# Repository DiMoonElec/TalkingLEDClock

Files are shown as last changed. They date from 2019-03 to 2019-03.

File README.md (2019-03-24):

# TalkingLEDClock
Говорящие LED-часы с будильником и термометром

Ссылки на статьи:
http://dimoon.ru/category/proektyi/talkingledclock

Структура проекта:  <br>
AT45Dump\ - все, что касается сборки дампа с музыкальными семплами <br>
PCB\ - схема + печатная плата <br>
STM32_Prg\tc_stm32.hex - прошивка МК часов <br>
STM32_Source\ - исходники прошивки часов <br>

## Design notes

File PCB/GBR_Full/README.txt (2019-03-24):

top.gbr - медь верх
mask_top.gbr - маска верх
silk_top.gbr - маркировка верх

bott.gbr - медь низ
mask_bott.gbr - маска низ
silk_bott.gbr - маркировка низ

border.gbr - граница платы

Through_circle.drl - сверловка круглые металлизированные отверстия
Through_ellipse.drl - фрезеровка овальные металлизированные отверстия
Through.drl - неметаллизированные крепежные отверстия

PCB.png - внешний вид заготовки с платами

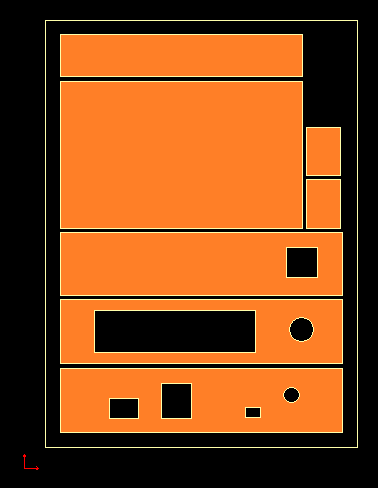
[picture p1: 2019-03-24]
PCB/GBR_Full/PCB.png

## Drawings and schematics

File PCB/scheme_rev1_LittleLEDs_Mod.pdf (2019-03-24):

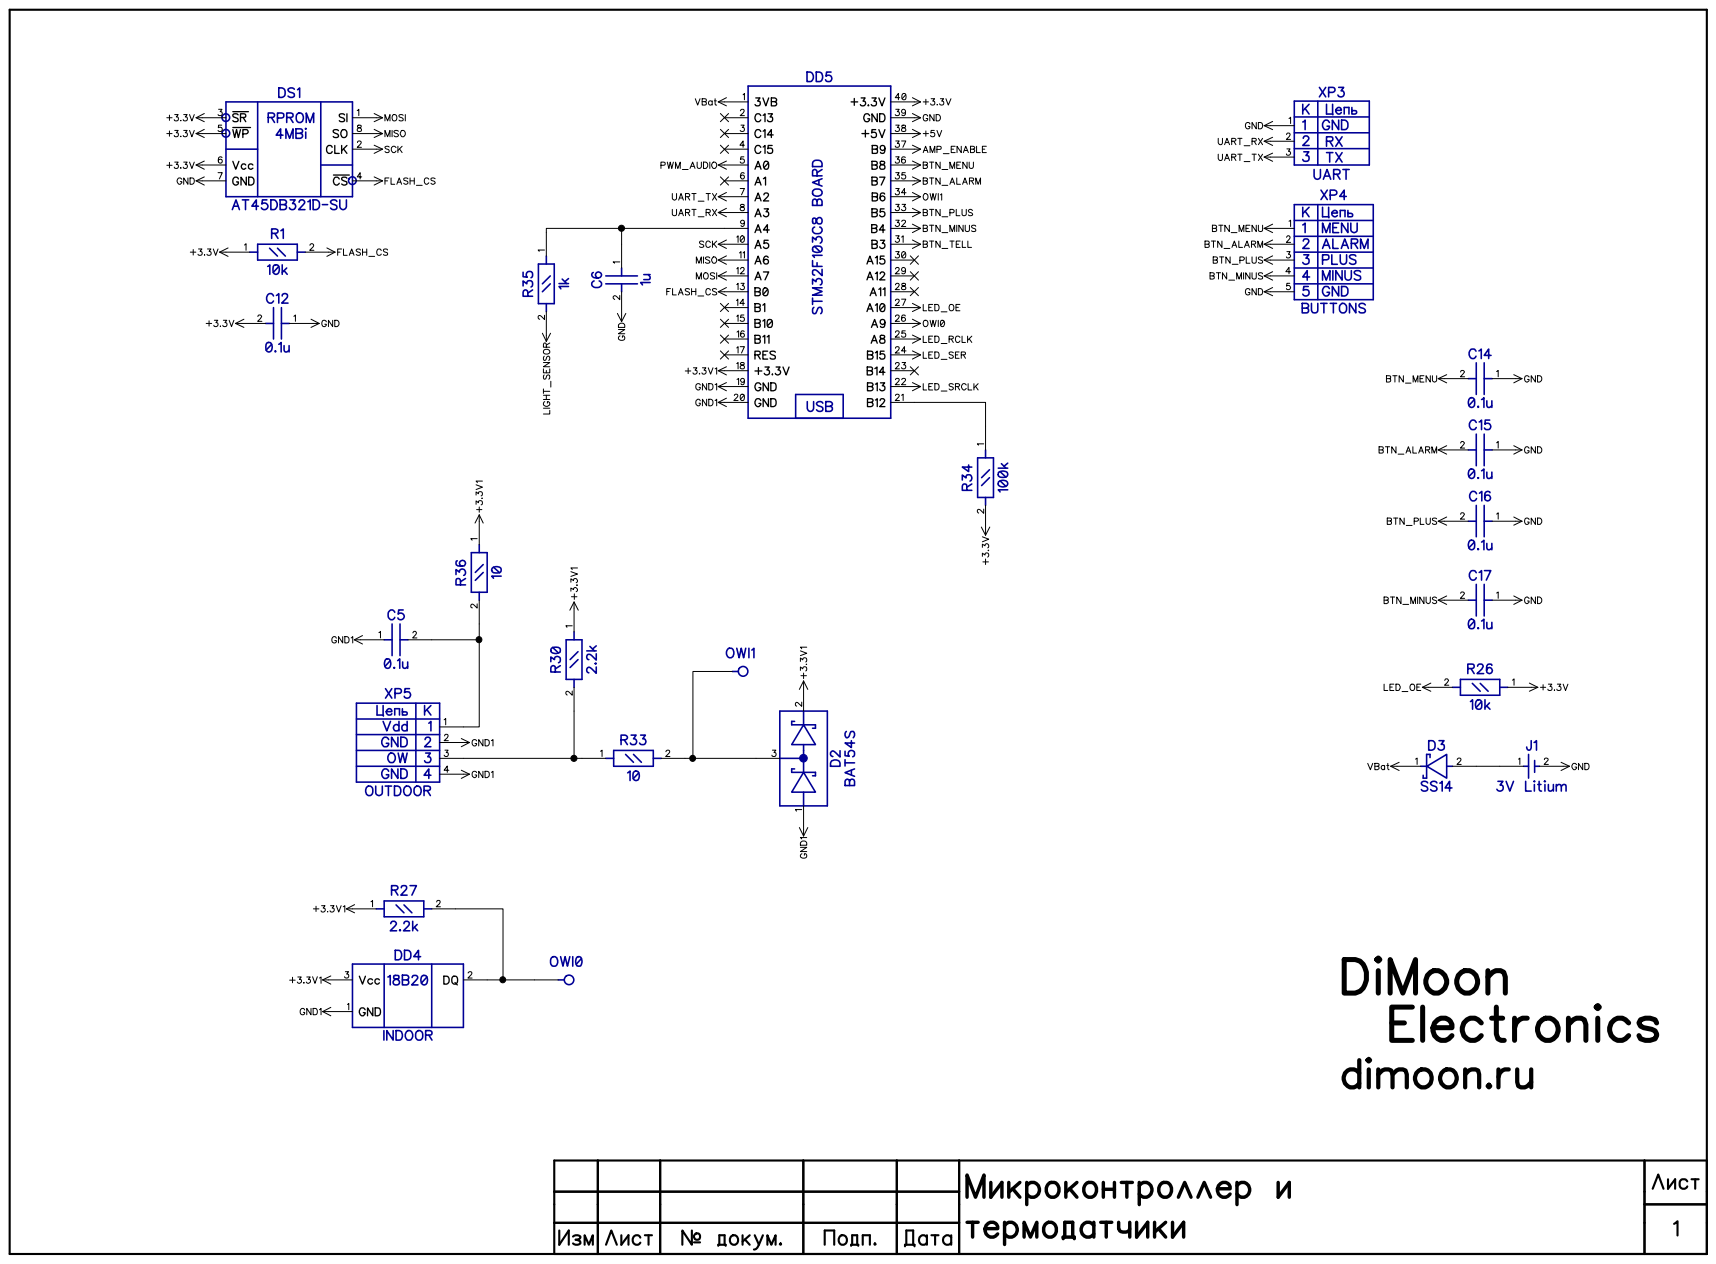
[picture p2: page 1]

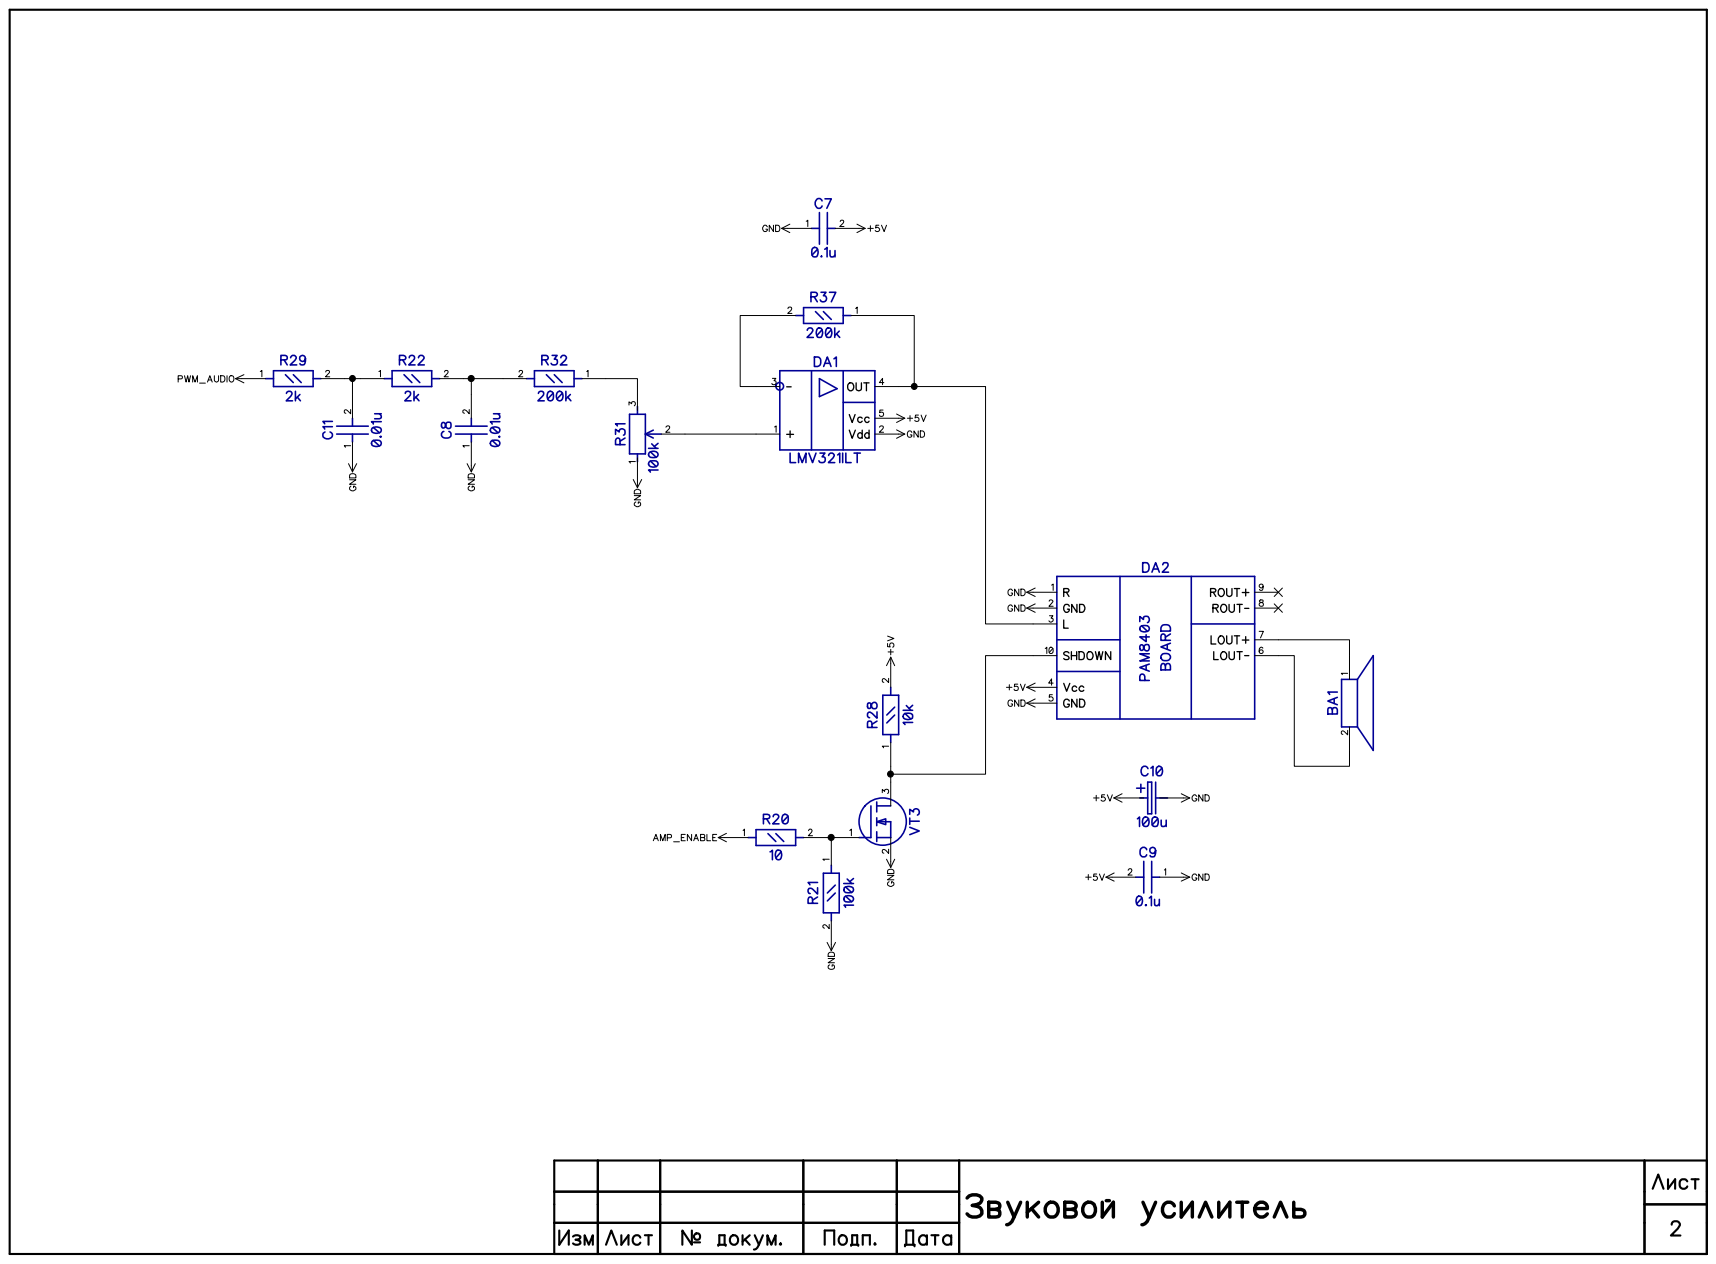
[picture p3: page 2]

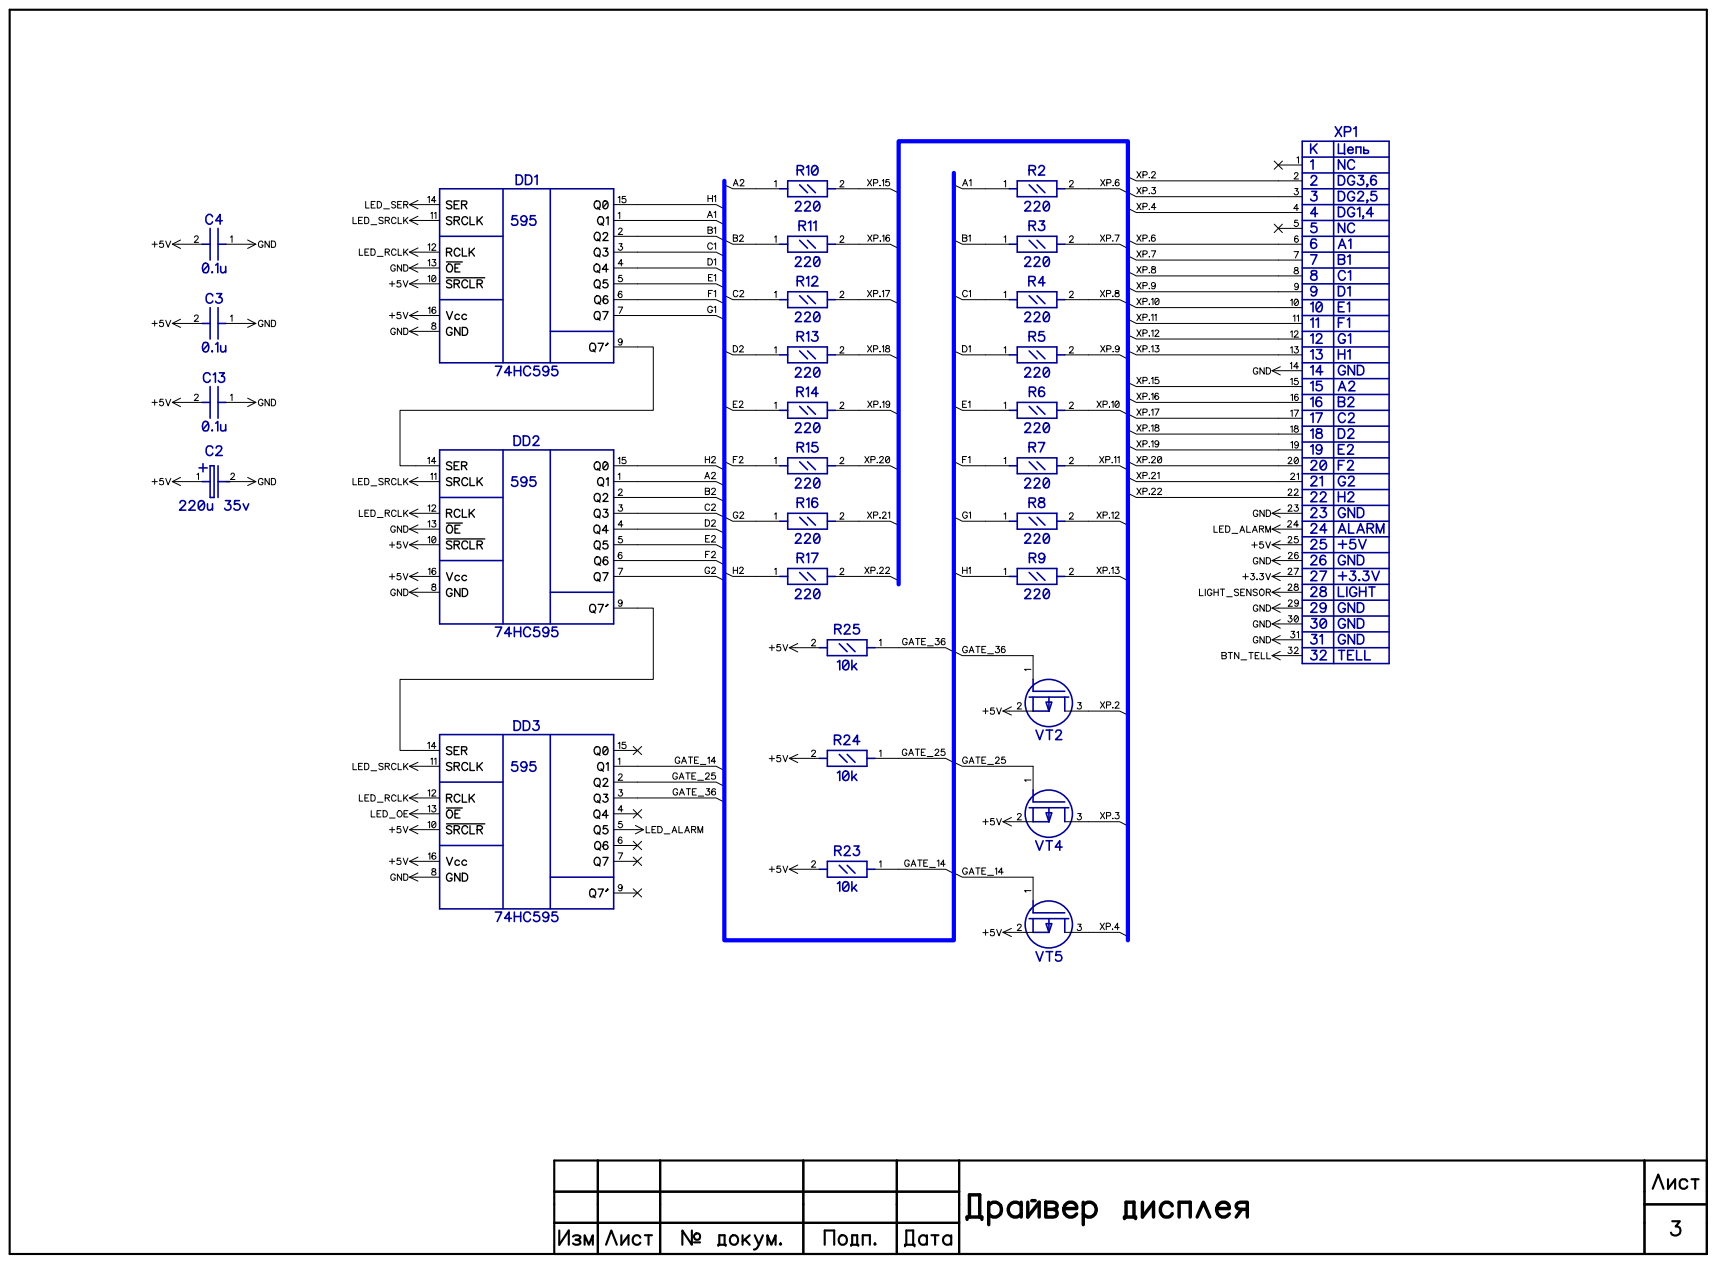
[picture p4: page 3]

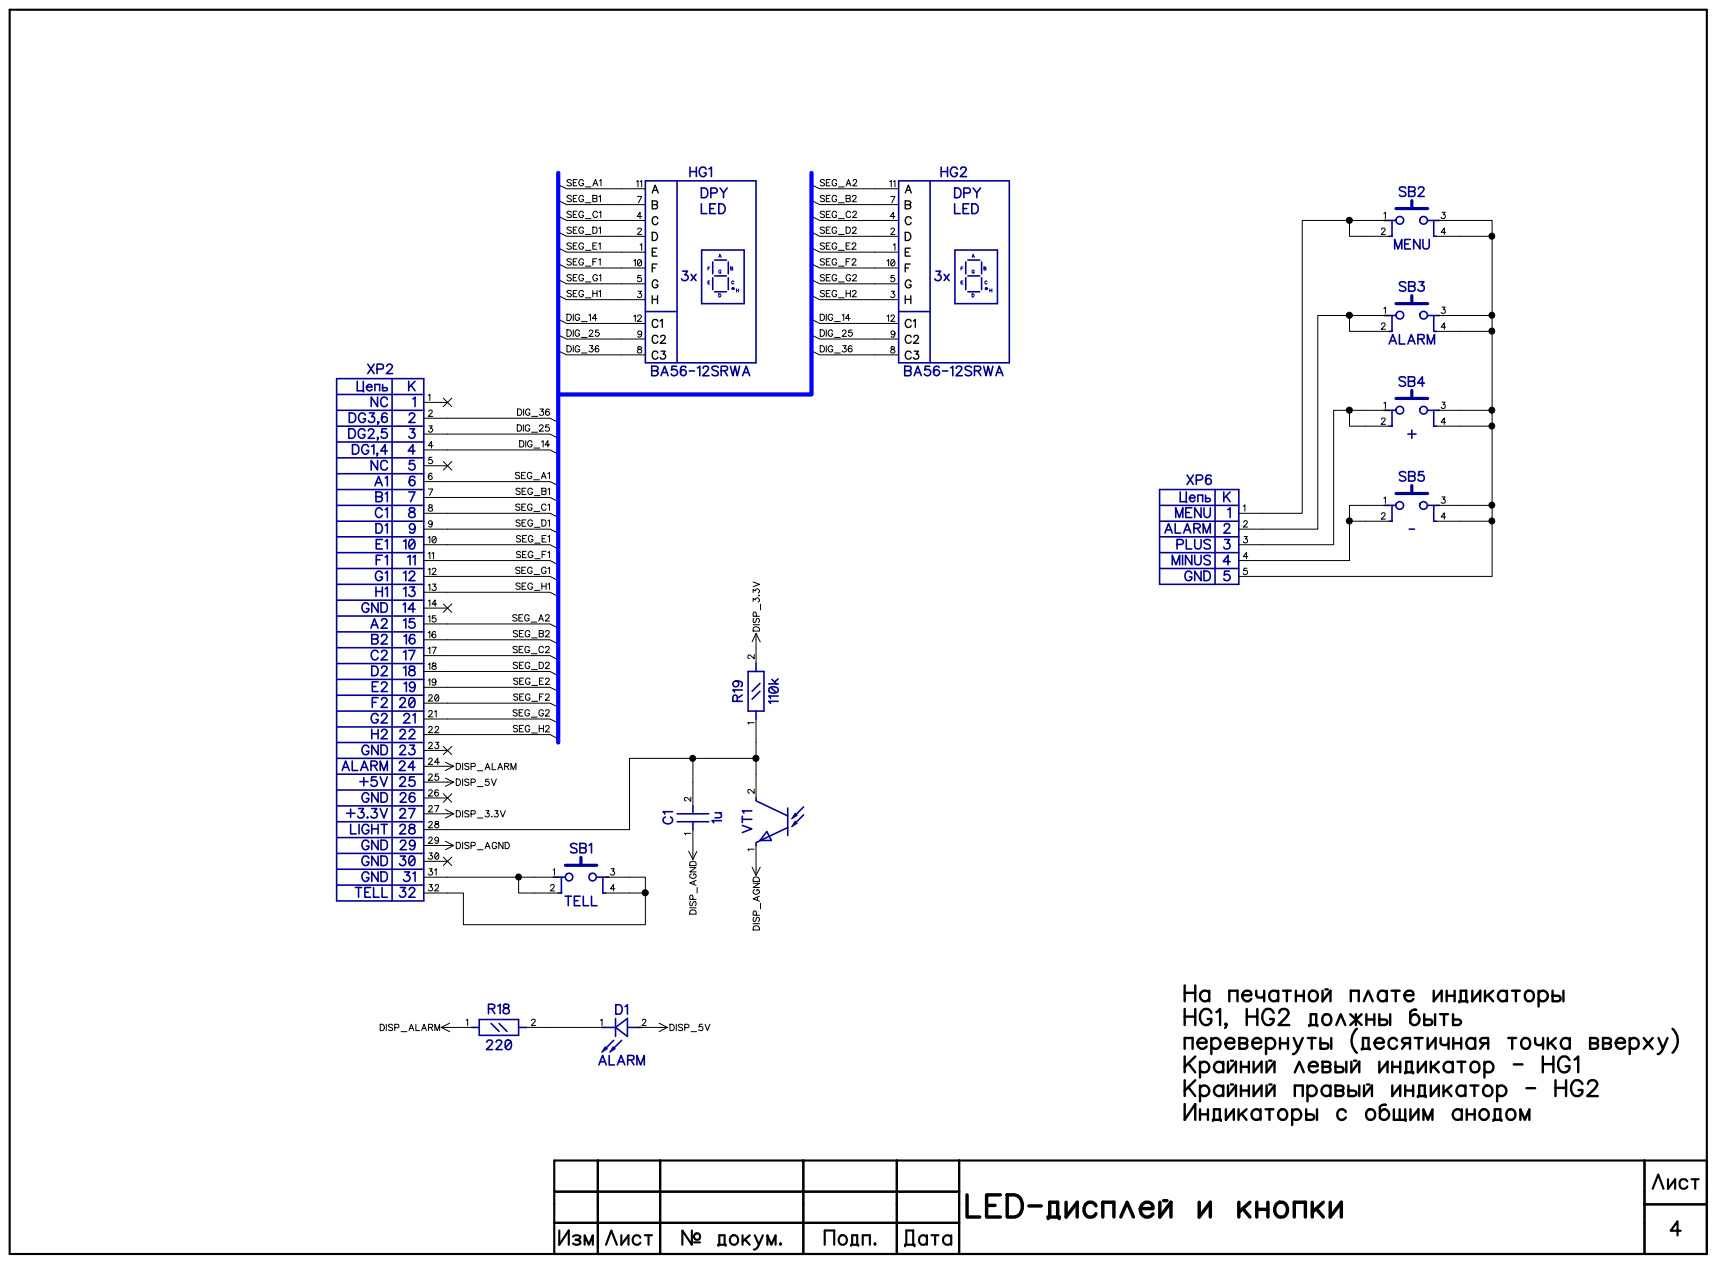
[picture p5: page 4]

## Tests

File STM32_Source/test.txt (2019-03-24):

#include <stdint.h>
#include "stm32f1xx.h"
#include "clock.h"
#include "watch_io.h"
#include "rtc.h"
#include "timers.h"

static unsigned char dec2bcdTens(unsigned char num){return num / 10;}
static unsigned char dec2bcdUnits(unsigned char num){return num % 10;}

void DisplayData(uint8_t data)
{
  LED_Set(0, dec2bcdTens(data));
  LED_Set(1, dec2bcdUnits(data));
  LED_Set(2, LED_SYMBOL_NULL);
  LED_Set(3, LED_SYMBOL_NULL);
  LED_Set(4, LED_SYMBOL_NULL);
  LED_Set(5, LED_SYMBOL_NULL);
}

//void DisplayTime(RTC_DateTimeTypeDef* RTC_DateTimeStruct)
void DisplayTime(RTC_Time* RTC_Time)
{
  LED_Set(0, dec2bcdTens(RTC_Time->RTC_Hours));
  LED_Set(1, dec2bcdUnits(RTC_Time->RTC_Hours));
  LED_Set(2, LED_SYMBOL_MINUS);
  LED_Set(3, dec2bcdTens(RTC_Time->RTC_Minutes));
  LED_Set(4, dec2bcdUnits(RTC_Time->RTC_Minutes));
  LED_Set(5, LED_SYMBOL_NULL);
}

int cntr99 = 0;

uint8_t b;

//RTC_DateTimeTypeDef rtc_time;

RTC_Time time;

uint16_t tmp;

void main(void)
{
  ClockInit();
  
  io_init();
  
  RTC_Init();
  
  InitTimers();
  
  /*
  time.RTC_Hours = 20;
  time.RTC_Minutes = 7;
  time.RTC_Seconds = 0;
  RTC_SetTime(&time);
  */
  BackupWrite(0, 0x13);
  BackupWrite(9, 0x16);
  BackupWrite(3, 0x66);
  
  tmp = BackupRead(0);
  tmp = BackupRead(9);
  tmp = BackupRead(3);
  tmp = BackupRead(2);

  /*
  LED_Set(0, 1);
  LED_Set(1, 2);
  LED_Set(2, LED_SYMBOL_MINUS);
  LED_Set(3, 4);
  LED_Set(4, 5);
  LED_Set(5, LED_SYMBOL_NULL);
  */
  uint8_t br = 10;
  LED_Brightness(br);

  //LED_BlinkOn(LED_BLINK_0 | LED_BLINK_1);
  LED_PointsSet(LED_POINT_ALARM);
  
  ButtonArptOn(BUTTON_2);
  ButtonArptOn(BUTTON_3);
  
  for(;;)
  {
    if(RTC_IsUpdate())
    {
      //RTC_GetDateTime(&rtc_time);
      //DisplayTime(&rtc_time);
      RTC_GetTime(&time);
      DisplayTime(&time);
    }
  }
  
  for(;;)
  {
    
    b = GetButton();
    if(b == BUTTON_5)
      LED_BlinkOff(LED_BLINK_0 | LED_BLINK_1);
    else if(b == BUTTON_4)
      LED_BlinkOn(LED_BLINK_0 | LED_BLINK_1);
    else if(b == BUTTON_3)
    {
      /*
      if(br != 0)
        br--;
      
      LED_Brightness(br);
      */
      if(cntr99 != 0)
        cntr99--;
      LED_BlinkTimerReset();
    }
    else if(b == BUTTON_2)
    {
      if(cntr99 != 99)
        cntr99++;
      LED_BlinkTimerReset();
      /*
      if(br != 17)
        br++;
      LED_Brightness(br);
      */
    }
    else if(b == BUTTON_1)
    {
      if(LED_Status() == 1)
        LED_Off();
      else
        LED_On();
    }
    /*
    LED_Brightness(b);
    b++;
    if(b>10)
      b = 2;
    */
    
    DisplayData(cntr99);
  }
}

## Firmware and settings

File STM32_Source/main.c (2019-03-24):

#include <stdint.h>
#include "stm32f1xx.h"
#include "clock.h"
#include "watch_io.h"
#include "rtc.h"
#include "timers.h"
#include "fsm_main.h"
#include "spi.h"
#include "at45db321.h"
#include "uart.h"
#include "loader.h"
#include "voice.h"
#include "temper.h"
#include "light_sensor.h"

static void flash_mode(void);
static int is_flash_mode(void);

void main(void)
{
  int status = is_flash_mode();
  ClockInit();
  
  //status = 1;
  if(status)
  {
    flash_mode();
  }  
  io_init();
  RTC_Init();
  
  //FSM init
  InitTimers();
  InitFSMMain();
  VoiceInit();
  
  InitTemper();
  
  InitLigthSensor();
  
  for(;;)
  {
    ProcessFSMMain();
    VoiceProcess();
    ProcessTemper();
    ProcessLigthSensor();
    __WFI();
  }
}




#define BUTTON_1_MSK    (1<<3)
#define BUTTON_2_MSK    (1<<4)
#define BUTTON_3_MSK    (1<<5)
#define BUTTON_4_MSK    (1<<8)
#define BUTTON_5_MSK    (1<<7)

static int is_flash_mode(void)
{
  RCC->APB2ENR |= RCC_APB2ENR_IOPBEN; //Включаем тактирование GPIOB
  RCC->APB2ENR |= RCC_APB2ENR_AFIOEN; //тактирование AFIO
  
  //Отключаем JTAG, так как он висит 
  //на используемых для кнопок пинах
  AFIO->MAPR |= (0x02<<AFIO_MAPR_SWJ_CFG_Pos); 
  
  //Выводы, к которым подключены кнопки:
  //PB3 - B1
  //PB4 - B2
  //PB5 - B3
  //PB8 - B4
  //PB7 - B5
  
  GPIOB->CRL &= ~(GPIO_CRL_CNF3 | GPIO_CRL_MODE3
                | GPIO_CRL_CNF4 | GPIO_CRL_MODE4
                | GPIO_CRL_CNF5 | GPIO_CRL_MODE5
                | GPIO_CRL_CNF7 | GPIO_CRL_MODE7);
  GPIOB->CRH &= ~(GPIO_CRH_CNF8 | GPIO_CRH_MODE8);
  
  //Настраиваем все выводы на вход с подтяжкой вверх
  GPIOB->CRL |= (0x02<<GPIO_CRL_CNF3_Pos
               | 0x02<<GPIO_CRL_CNF4_Pos
               | 0x02<<GPIO_CRL_CNF5_Pos
               | 0x02<<GPIO_CRL_CNF7_Pos);
  GPIOB->CRH |= (0x02<<GPIO_CRH_CNF8_Pos);
  
  GPIOB->ODR |= (BUTTON_1_MSK 
               | BUTTON_2_MSK 
               | BUTTON_3_MSK 
               | BUTTON_4_MSK 
               | BUTTON_5_MSK);
  
  
  for(int i=0; i<10000; i++)
    asm("nop");
  
  uint16_t tmp = GPIOB->IDR; //сохраняем значение порта
  tmp ^= 0xFFFF;
  
  RCC->APB2RSTR |= (RCC_APB2RSTR_IOPBRST | RCC_APB2RSTR_AFIORST);
  RCC->APB2RSTR &= ~(RCC_APB2RSTR_IOPBRST | RCC_APB2RSTR_AFIORST);
  
  RCC->APB2ENR &= ~RCC_APB2ENR_IOPBEN; //Отключаем тактирование GPIOB
  RCC->APB2ENR &= ~RCC_APB2ENR_AFIOEN; //тактирование AFIO
  
  
  if((tmp & BUTTON_2_MSK) && (tmp & BUTTON_5_MSK)
     && (!(tmp & BUTTON_1_MSK)) && (!(tmp & BUTTON_3_MSK)) && (!(tmp & BUTTON_4_MSK)))
    return 1;
  
  return 0;
  
}

static void flash_mode(void)
{
  //LED_Set(5, 1);
  loader_run();
  
  for(;;)
  {
    ;
  }
  
}

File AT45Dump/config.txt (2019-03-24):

; Test configuration file
; for build TalkingClock_v1.1 dump file

SAMPLE_0 =      "wav\0.wav"
SAMPLE_1m =     "wav\1m.wav"
SAMPLE_1w =     "wav\1w.wav"
SAMPLE_2m =     "wav\2m.wav"
SAMPLE_2w =     "wav\2w.wav"
SAMPLE_3 =      "wav\3.wav"
SAMPLE_4 =      "wav\4.wav"
SAMPLE_5 =      "wav\5.wav"
SAMPLE_6 =      "wav\6.wav"
SAMPLE_7 =      "wav\7.wav"
SAMPLE_8 =      "wav\8.wav"
SAMPLE_9 =      "wav\9.wav"
SAMPLE_10 =     "wav\10.wav"
SAMPLE_11 =     "wav\11.wav"
SAMPLE_12 =     "wav\12.wav"
SAMPLE_13 =     "wav\13.wav"
SAMPLE_14 =     "wav\14.wav"
SAMPLE_15 =     "wav\15.wav"
SAMPLE_16 =     "wav\16.wav"
SAMPLE_17 =     "wav\17.wav"
SAMPLE_18 =     "wav\18.wav"
SAMPLE_19 =     "wav\19.wav"
SAMPLE_20 =     "wav\20.wav"
SAMPLE_30 =     "wav\30.wav"
SAMPLE_40 =     "wav\40.wav"
SAMPLE_50 =     "wav\50.wav"
SAMPLE_rovno =  "wav\rovno.wav"
SAMPLE_chas =   "wav\chas.wav"
SAMPLE_chasov = "wav\chasov.wav"
SAMPLE_chasa =  "wav\chasa.wav"
SAMPLE_minut =  "wav\minut.wav"
SAMPLE_minuta = "wav\minuta.wav"
SAMPLE_minuty = "wav\minuty.wav"
SAMPLE_bell =   "wav\bell.wav"
SAMPLE_minus =           "wav\minus.wav"
SAMPLE_gradus =          "wav\gradus.wav"
SAMPLE_gradusa =         "wav\gradusa.wav"
SAMPLE_gradusov =        "wav\gradusov.wav"
SAMPLE_temperatura_out = "wav\temperatura_out.wav"
SAMPLE_temperatura_in =  "wav\temperatura_in.wav"

SAMPLE_alarm1 = "wav\katusha.wav"
SAMPLE_alarm2 = "wav\chip_i_deil.wav"
SAMPLE_alarm3 = "wav\Pirates.wav"
SAMPLE_alarm4 = "wav\ku-ka-re-ku.wav"
SAMPLE_alarm5 = "wav\alarm_electro.wav"
SAMPLE_alarm6 = "wav\alarm_radioclock.wav"
SAMPLE_alarm7 = ""
SAMPLE_alarm8 = ""
SAMPLE_alarm9 = ""
SAMPLE_alarm10 = ""
SAMPLE_alarm11 = ""
SAMPLE_alarm12 = ""
SAMPLE_alarm13 = ""
SAMPLE_alarm14 = ""
SAMPLE_alarm15 = ""
SAMPLE_alarm16 = ""

; End of file

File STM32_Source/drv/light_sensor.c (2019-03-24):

#include <stdint.h>
#include "stm32f1xx.h"
#include "timers.h"
#include "light_sensor.h"

/*
  Используемая периферия 
    ADC1
    PA4
*/

#define ADC_ENABLE()    ADC1->CR2 |= ADC_CR2_ADON
#define ADC_DISABLE()   ADC1->CR2 &= ADC_CR2_ADON

#define ADC_CONVERT()    ADC1->CR2 |= ADC_CR2_ADON

#define ADC_DATA         ADC1->DR


#define WIN_SIZE        8
static uint16_t ma_array[WIN_SIZE];
static uint8_t ma_index = 0;

////////////////////////////

static uint8_t state;
//static uint8_t light_val;
static IllumLevel_t light_val;

////////////////////////////

//Инициализация фильтров
static void ma_init(void)
{
  ma_index = 0;
  
  for(int i=0; i<WIN_SIZE; i++)
  {
    ma_array[i] = 0;
  }
}

//Добавить новое значение в фильтр
static void ma_add(uint16_t val)
{
  ma_array[ma_index] = val;
  
  ma_index++;
  if(ma_index >= WIN_SIZE)
    ma_index = 0;
}

//плучить сглаженное значение
static uint16_t ma_get(void)
{
  uint32_t tmp = 0;
  for(int i = 0; i<WIN_SIZE; i++)
  {
    tmp += ma_array[i];
  }
  
  return tmp / WIN_SIZE;
}

///////////////////////////


static void adc_init(void)
{
  RCC->APB2ENR |= RCC_APB2ENR_IOPAEN;
  RCC->APB2ENR |= RCC_APB2ENR_ADC1EN;
  
  //GPIO init
  //PA4 - Analog mode
  GPIOA->CRL &= ~(GPIO_CRL_CNF4 | GPIO_CRL_MODE4);
  
  //ADC1 init
  RCC->CFGR |= (0x03 << RCC_CFGR_ADCPRE_Pos); //предделитель ADC
  ADC1->SQR3 = (0x04 << ADC_SQR3_SQ1_Pos);
  ADC1->SQR1 = 0;
  
  //calibration
  ADC_ENABLE();
  
  for(int i=0; i<100000; i++)
    ;
  ADC1->CR2 |= ADC_CR2_CAL;
  
  while(ADC1->CR2 & ADC_CR2_CAL)
    ;
}


static void ADC2Light(uint16_t adc_val)
{
  //пропускаем значение АЦП через скользящее среднее
  ma_add(adc_val);
  uint32_t ma_val = ma_get();
  
  
  if(ma_val <= ILLUM_LIGHT_H) //проверка границ "Светло"
  {
    light_val = ILLUM_LIGHT; //светло
  }
  else if(ma_val >= ILLUM_MEDIUM_L && ma_val <= ILLUM_MEDIUM_H) //проверка границ "Средне"
  {
    light_val = ILLUM_MEDIUM; //средне
  }
  else if(ma_val >= ILLUM_DARK_L && ma_val <= ILLUM_ADC_MAX_VAL) //проверка границ "Темно"
  {
    light_val = ILLUM_DARK; //темно
  }
  //проверка корректного значения неопределенных областей
  else if((ma_val > ILLUM_LIGHT_H && ma_val < ILLUM_MEDIUM_L) //Если находимся между "Светло" и "Средне", 
          && (light_val != ILLUM_LIGHT && light_val != ILLUM_MEDIUM)) //но предыдущее значение освещенности не "Светло" и не "Средне",
  {
    light_val = ILLUM_LIGHT; //то исправляем это на значение "Светло"
  }
  else if((ma_val > ILLUM_MEDIUM_H && ma_val < ILLUM_DARK_L) //Если между "Средне" и "Темно"
          && (light_val != ILLUM_MEDIUM && light_val != ILLUM_DARK)) //но предыдущее значение не "Средне" и не "Темно"
  {
    light_val = ILLUM_MEDIUM; //то исправляем на "Средне"
  }
           
  
  
  //Старая реализация датчика освещенности
  /*
  ma_add(adc_val);
  
  int32_t tmp = ma_get();
  
  tmp -= light_val*16; //реализация гистерезиса срабатывания уровней
  
  if(tmp > 3999)
    light_val = 0; //темно
  else if(tmp > 2400) //2400
    light_val = 1; //сумерки
  else
    light_val = 2; //светло
  */
}


void InitLigthSensor(void)
{
  adc_init();
  state = 0;
  //light_val = 0;
  light_val = ILLUM_DARK;
  ma_init();
}



void ProcessLigthSensor(void)
{
  switch(state)
  {
  case 0:
    ResetTimer(TIMER_LIGHT_SENSOR);
    ADC_CONVERT();
    state = 1;
    break;
    
  case 1:
    if(GetTimer(TIMER_LIGHT_SENSOR) >= (TMR_SEC / 10))
    {
      ADC2Light(ADC_DATA);
      state = 0;
    }
    break;
    
  default:
    state = 0;
    break;
  }
}

IllumLevel_t LigthSensorVal(void)
{
  return light_val;
}
